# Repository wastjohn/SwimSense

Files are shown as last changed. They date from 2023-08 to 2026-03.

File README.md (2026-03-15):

# SwimSense
The goal of this project is to provide swimmers and coaches with all the resources they need to analyze their swimming technique through data. This project arose out of a desire of mine to improve my own technique, and was inspired by the work of [Ken Ono and others with the University of Vrigina's Swim Team](https://datascience.virginia.edu/news/how-science-math-and-tech-can-propel-swimmers-new-heights).

More sophisticated products exist that allow swimmers and coaches to analyze their technique through sensors, but the products are expensive and inexcessible to most. When I was looking for products, I came across this issue, which is why I designed this project to be open-source. The materials themselves are low-cost (especially compared to current products on the market), and the assembly is simple. A full guide to get started building your own prototype is included below. If you find any issues, please create a GitHub issue and I will try and fix it as soon as I can.

> NOTE: This project is under active development.

# Guide
## Prototype
### Materials (Total Cost: ~$78)
- 1 x [Adafruit Feather RP2040 Adalogger with Micro SD card](https://www.adafruit.com/product/5980) ~$15
- 1 x [Micro SD card](https://a.co/d/egYFXCA) ~$20
- 1 x [Adafruit MPU-6050 6-DoF Accel and Gyro Sensor - STEMMA QT Qwiic](https://www.adafruit.com/product/3886?srsltid=AfmBOopC2_q72G2jyYriWZb89m_ki3SGv5NjMLReuicTID7EJPNb-SiP) ~$13
- 1 x [Stemma QT connectors](https://www.adafruit.com/product/4399) ~$1
- 1 x [Lithium Ion Polymer Battery with Short Cable - 3.7V 420mAh](https://www.adafruit.com/product/4236) ~$7
- 1 x [USB-C to USB-C connector (for bootloading)](https://a.co/d/i387Y5Y) ~$7
- 1 x [UCO Waterproof Matchstick Case](https://a.co/d/2ja3F77) ~$6
- 1 x [T-REX Heavy Duty Waterproof Tape](https://a.co/d/hECwmLk) ~$9

### Assembly and Setup
Purchase all materials above.

<details>
<summary>What did I just buy and why do I need it?</summary>
<br>
TODO
</details>

#### Bootload the Microcontroller
1. Connect the microcontroller to your computer via the USB-C to USB-C cable
2. An LED on the microcontroller should light up
3. Hold the two buttons down on the microcontroller
4. The LED should change colors/flash and a new drive should pop up on your computer named RPI-RP2

<details>
<summary>What is bootloading?</summary>
<br>
TODO
</details>

#### Download the Arduino IDE and Write the Code
1. [Navigate to the Arduino Website](https://www.arduino.cc/en/software/) and download the most recent version of their IDE.
2. Open the IDE.
3. Nagivate to the Library Manager tab and download the following packages
   1. Package 1
   2. Package 2
   3. Package 3 (Note: Include pictures of these steps)
4. 

<details>
<summary>What is an IDE? Arduino?</summary>
<br>
TODO
</details>

#### Test the Sensor

#### 3D Printed Parts

#### Assemble!

# Current Progress
Successfully recorded 2 swims. One is a full 25 yd swim.


The other is a full 50 yd swim.


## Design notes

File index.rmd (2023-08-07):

---
title: "Swim Accelerometer Visualization"
author: "Will St. John"
date: "Summer 2023"
output: 
    html_document:
        toc: FALSE
        toc_float: FALSE
---
## Goals
The goal of this project is to display 4 windows:

- Video of an accelerometer session
- X acceleration of that accelerometer session
- Y acceleration of that accelerometer session
- Z acceleration of that accelerometer session

## Layout
The 4 frames will have the following layout:

```{python, echo=FALSE}
temp = [
    '______________________',
    '|                    |',
    '|        video       |',
    '|____________________|',
    '|   x  |   y  |   z  |',
    '|______|______|______|']
for i in temp:
    print(i)
```

As the video plays, the X, Y, and Z windows should display the corresponding acceleration at the given time +/- a few seconds. Since the three plots are touching, the y-axis should only be shown on the left-most pannel.

## Visualizations

```{r, include=FALSE}
library(ggplot2)
library(plotly)
library(htmlwidgets)
library(lubridate)
```

```{r}
file <- 'Rec_0614_055549_clean.txt'
df <- read.csv(file, sep = '\t', skip = 1)
head(df)
df$TIME2 <- hms(df$Time)
```

```{r}
p <- ggplot(df, aes(x = Time, y = ax)) +
        geom_point(color = 'steelblue', size = 1) +
        geom_line(color = 'steelblue')
p
```

```{r}
str(df$ax)
str(df$Time)
```

```{python, echo=FALSE}
#import main
import tkinter as tk

```

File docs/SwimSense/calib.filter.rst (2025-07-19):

calib.filter
============

.. automodule:: calib.filter

   .. rubric:: Classes

   .. autosummary::
   
      KalmanFilter

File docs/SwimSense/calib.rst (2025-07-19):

calib
=====

.. automodule:: calib

.. rubric:: Modules

.. autosummary::
   :toctree:
   :recursive:

   filter

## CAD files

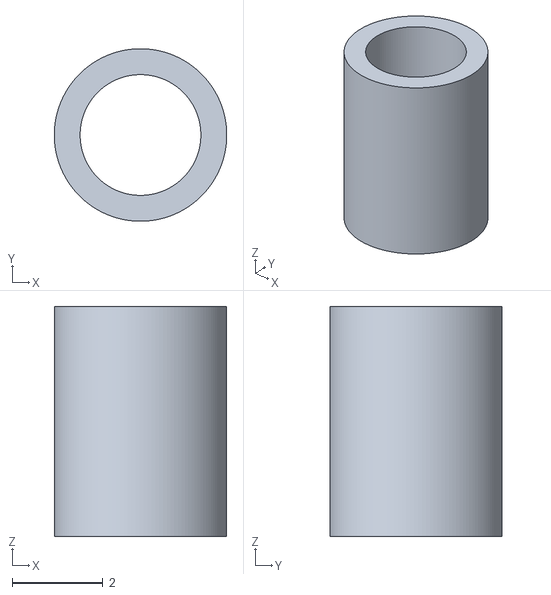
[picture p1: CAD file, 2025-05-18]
src/STL/standoff.stl
3.81 x 3.81 x 5.08

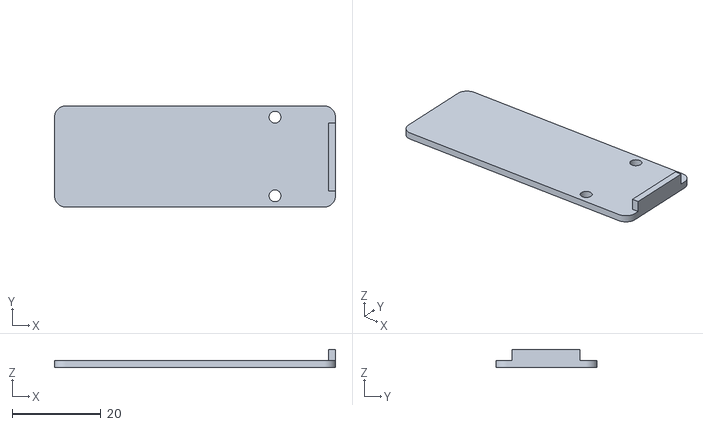
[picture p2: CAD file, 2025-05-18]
src/STL/Spacer plate.stl
63.5 x 22.9 x 4.11

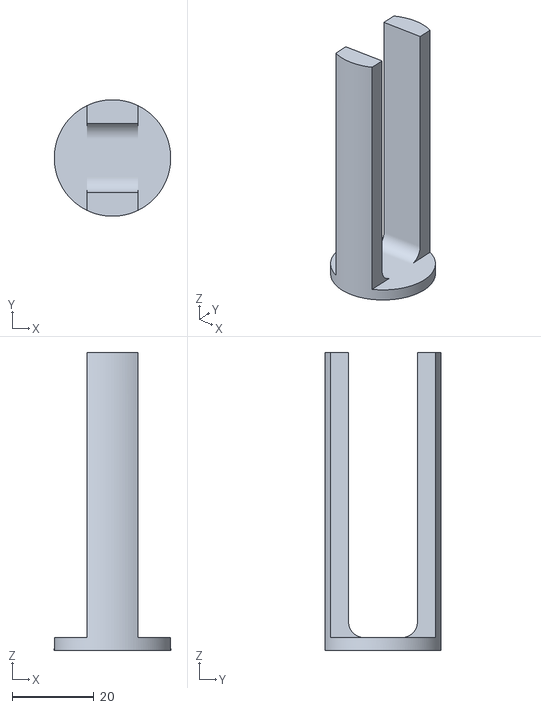
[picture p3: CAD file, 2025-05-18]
src/STL/cradle.stl
28.5 x 28.5 x 73.0

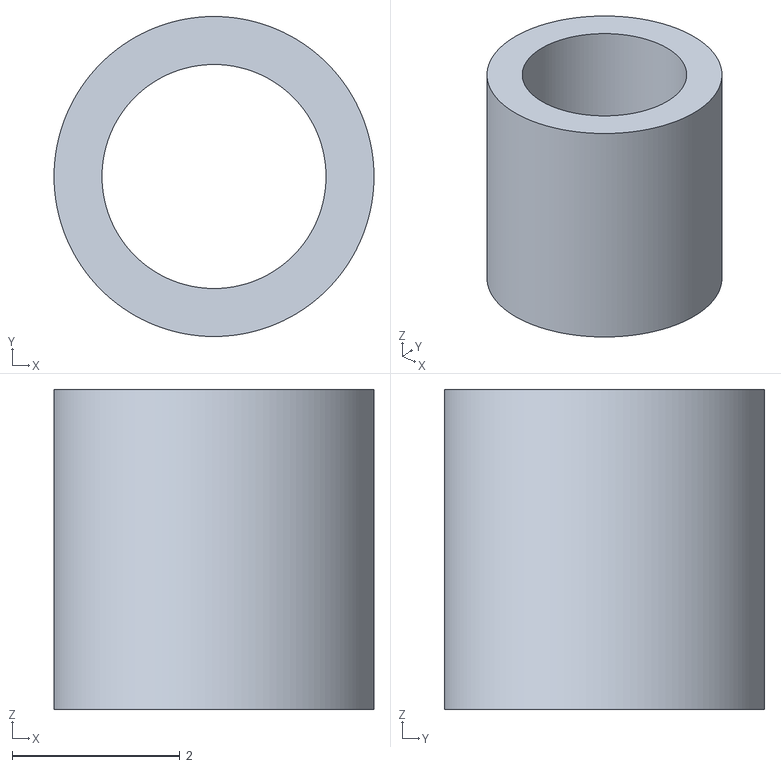
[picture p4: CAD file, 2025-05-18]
src/STL/short standoff.stl
3.81 x 3.81 x 3.81

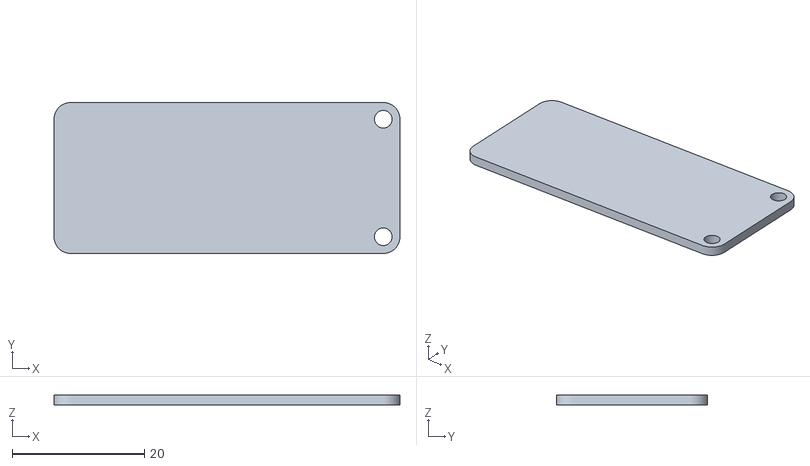
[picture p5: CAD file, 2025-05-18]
src/STL/middle spacer.stl
52.4 x 22.9 x 1.57

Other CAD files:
src/STL/Short spacer plate.stl

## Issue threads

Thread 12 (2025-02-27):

Purchase materials, bootload/program microcontroller, assemble prototype

wastjohn, 2025-02-27:
Research what components we will need for this project and purchase them. Setup the microcontroller so that it can be programmed (bootload) and connect it to the IMU sensor.

Closed 2025-04-06.

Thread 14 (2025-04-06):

Purchase LiPo battery for prototype

wastjohn, 2025-04-06:
[Use this link](https://learn.adafruit.com/adafruit-feather-rp2040-adalogger/power-management)

Closed 2025-05-18.

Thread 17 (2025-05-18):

Add boot button and SD card safeties

wastjohn, 2025-05-18:
Write to SD continuously, then close the SD card under the following three conditions:

- Button press to unmount the card
- Low battery voltage
- SD card is getting full

Closed 2025-07-02.

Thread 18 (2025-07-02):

Calculate offset values

wastjohn, 2025-07-02:
In a stationary position, record 500 samples of acceleration and rotation to calculate the offset values for the sensor

wastjohn, 2025-07-02:
Calculated the median value from 825 samples saved to `data/offsets/offset0.csv`. Is currently implemented in the data analysis section of the dashboard.

Closed 2025-07-02.

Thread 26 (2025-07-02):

Capture video and sensor data of a full 50yd swim

wastjohn, 2025-07-02:
Procedure:

1. Start the video before turning the sensor on
2. Turn the sensor on
3. Put the sensor in the belt (this should look similar to issue #19 in the analysis)
4. Perform a jump (should look similar to issue #20 in the analysis)
5. Enter the water smoothly from the side and perform dolphin kicks (should look like #23 and #22)
6. Execute a flip turn (look like #25, #23, and #22)
7. Finish to the wall
8. Exit the water
9. Remove the sensor from the belt
10. Power off the sensor
11. End the video

wastjohn, 2025-07-18:
Success with WJ!

Closed 2025-07-18.

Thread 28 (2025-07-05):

Find a more waterproof solution to the current prototype.

wastjohn, 2025-07-05:
Currently we use a poor-man's vacuum seal with a Ziploc bag around the screwed shut matchstick holder. The vacuum seal is imperfect and so is the matchstick holder. Maybe there's another solution that is entirely 3D printed...

wastjohn, 2025-07-09:
I put T-Rex tape around the threads of the prototype. The seal improved, but opening and closing the container damages the seal. I'm going to test the seal with the sensor for another swim, but this feels like a temporary solution.

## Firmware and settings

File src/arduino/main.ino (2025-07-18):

/*
File: main.ino

This script reads from a sensor and saves to an SD card.

Author: Will St. John, David Bailey
Summer 2025
*/

#include <Adafruit_MPU6050.h>
#include <Adafruit_Sensor.h>
#include <Wire.h>
#include <SPI.h>
#include "SdFat.h"

#define SD_CS_PIN 23
#define startButton PIN_BUTTON
#define led LED_BUILTIN
// #define npled PIN_NEOPIXEL
#define holdTime 2000
unsigned long timePressed = 0;

Adafruit_MPU6050 mpu;
SdFat SD;
FsFile dataFile;
SdSpiConfig config(SD_CS_PIN, DEDICATED_SPI, SD_SCK_MHZ(16), &SPI1);



//////////////// helpful functions ////////////////

void waitForStartButton() {  //wait until the button is pressed for 2 seconds
  while (true) {
    if (digitalRead(startButton) == LOW) {  //button is pressed
      if (timePressed == 0) {
        timePressed = millis();                         //start timing the button press
      } else if (millis() - timePressed >= holdTime) {  //button has been pressed for 2 seconds, return from loop
        timePressed = 0;
        for (int x = 0; x < 3; x++) {
          digitalWrite(led, HIGH);
          delay(500);
          digitalWrite(led, LOW);
          delay(500);
        }
        return;
      }
    } else {
      // Reset if button is released before 2 seconds
      timePressed = 0;
    }
  }
}




void closeSDcard() {  //close file function
  dataFile.close();
  Serial.println("Closed SD card.");
  delay(200);
  digitalWrite(led, HIGH);
  while (1) {
    digitalWrite(led, millis() % 500 > 250);  //halt program flash LED on and off every half second, indicates card not mounted
  }
}



//////////////// Microcontroller Setup ////////////////

void setup(void) {
  Serial.begin(115200);
  pinMode(led, OUTPUT);  // configure led to be able to flash
  
  Serial.println("Powered on. Waiting for start button.");
  waitForStartButton();

  while (!SD.begin(config)) {
    Serial.println("initialization failed! Retrying...");
    delay(1000); // Wait for a second before retrying
  }
  Serial.println("initialization done.");
  
  if (!SD.exists("swimdata.csv")) {  //create the file if it doesn't already exist
    dataFile = SD.open("swimdata.csv", FILE_WRITE);
  } else {
    dataFile = SD.open("swimdata.csv", FILE_WRITE | O_APPEND);  //append to existing file, mark as "new session"
    if (dataFile) {
      dataFile.println(" ");
      dataFile.print("New session");
      dataFile.print("\n");
      //Serial.print("\n");
    }
  }

  // Try to initialize!
  if (!mpu.begin()) {
    Serial.println("Failed to find MPU6050 chip");
    while (1) {
      delay(10);
    }
  }
  Serial.println("MPU6050 Found!");

  mpu.setAccelerometerRange(MPU6050_RANGE_8_G);
  Serial.print("Accelerometer range set to: ");
  switch (mpu.getAccelerometerRange()) {
  case MPU6050_RANGE_2_G:
    Serial.println("+-2G");
    break;
  case MPU6050_RANGE_4_G:
    Serial.println("+-4G");
    break;
  case MPU6050_RANGE_8_G:
    Serial.println("+-8G");
    break;
  case MPU6050_RANGE_16_G:
    Serial.println("+-16G");
    break;
  }
  mpu.setGyroRange(MPU6050_RANGE_500_DEG);
  Serial.print("Gyro range set to: ");
  switch (mpu.getGyroRange()) {
  case MPU6050_RANGE_250_DEG:
    Serial.println("+- 250 deg/s");
    break;
  case MPU6050_RANGE_500_DEG:
    Serial.println("+- 500 deg/s");
    break;
  case MPU6050_RANGE_1000_DEG:
    Serial.println("+- 1000 deg/s");
    break;
  case MPU6050_RANGE_2000_DEG:
    Serial.println("+- 2000 deg/s");
    break;
  }

  mpu.setFilterBandwidth(MPU6050_BAND_21_HZ);
  Serial.print("Filter bandwidth set to: ");
  switch (mpu.getFilterBandwidth()) {
  case MPU6050_BAND_260_HZ:
    Serial.println("260 Hz");
    break;
  case MPU6050_BAND_184_HZ:
    Serial.println("184 Hz");
    break;
  case MPU6050_BAND_94_HZ:
    Serial.println("94 Hz");
    break;
  case MPU6050_BAND_44_HZ:
    Serial.println("44 Hz");
    break;
  case MPU6050_BAND_21_HZ:
    Serial.println("21 Hz");
    break;
  case MPU6050_BAND_10_HZ:
    Serial.println("10 Hz");
    break;
  case MPU6050_BAND_5_HZ:
    Serial.println("5 Hz");
    break;
  }

  Serial.println("");
  delay(100);


}


//////////////// Data logging loop ////////////////

void loop() {
  //// Close SD card logic
  if (digitalRead(startButton) == LOW) {  //button is pressed
    if (timePressed == 0) {
      timePressed = millis();
    } else if (millis() - timePressed >= holdTime) {  //button has been pressed for 2 seconds, exit the loop and close SD card
      closeSDcard();
    }
  } else {
    timePressed = 0;  //reset time if button is released before 2 seconds
  }

  //// Check if there is enough space on the SD card before continuing
  uint32_t freeSpace = SD.freeClusterCount();  // Get the available clusters on the SD card
  if (freeSpace < 2) {  // Example: if fewer than 2 clusters are available, the card is nearly full
    // Handle SD card full condition: close the SD card and halt further operations
    closeSDcard();
  }

  /* Get new sensor events with the readings */
  sensors_event_t a, g, temp;
  mpu.getEvent(&a, &g, &temp);

  /* Print out the values to serial monitor */
  // Serial.print("t:");
  // Serial.print(millis());
  // Serial.print(",");

  // Serial.print("ax:");
  // Serial.print(a.acceleration.x);
  // Serial.print(",");

  // Serial.print("ay:");
  // Serial.print(a.acceleration.y);
  // Serial.print(",");

  // Serial.print("az:");
  // Serial.print(a.acceleration.z);
  // Serial.print(",");

  // Serial.print("gx:");
  // Serial.print(g.gyro.x);
  // Serial.print(",");

  // Serial.print("gy:");
  // Serial.print(g.gyro.y);
  // Serial.print(",");

  // Serial.print("gz:");
  // Serial.println(g.gyro.z);

  /* Write out the values to the SD card */
  
  dataFile.print(millis());
  dataFile.print(",");

  dataFile.print(a.acceleration.x);
  dataFile.print(",");

  dataFile.print(a.acceleration.y);
  dataFile.print(",");

  
  dataFile.print(a.acceleration.z);
  dataFile.print(",");

  dataFile.print(g.gyro.x);
  dataFile.print(",");

  dataFile.print(g.gyro.y);
  dataFile.print(",");

  dataFile.println(g.gyro.z);

  dataFile.flush();
  delay(15);
}

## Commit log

2025-05-18 STL files
    [Short spacer plate.stl, Spacer plate.stl, cradle.stl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]
2025-05-27 code with button control
2025-06-14 c++ arduino code implement
2025-07-18 ICF and WJ swims and directory cleanup
    [full25swim.csv, full25ydswim.csv, full50swim.csv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]
2025-07-19 project reorganization and docs
    [Short spacer plate.stl, Spacer plate.stl, cradle.stl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]
